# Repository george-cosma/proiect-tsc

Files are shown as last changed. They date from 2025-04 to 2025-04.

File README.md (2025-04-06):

# Openbook - Proiect TSC - by Cosma George

Exploded view

## Block Diagram

Block Diagram

## Overview ESP32

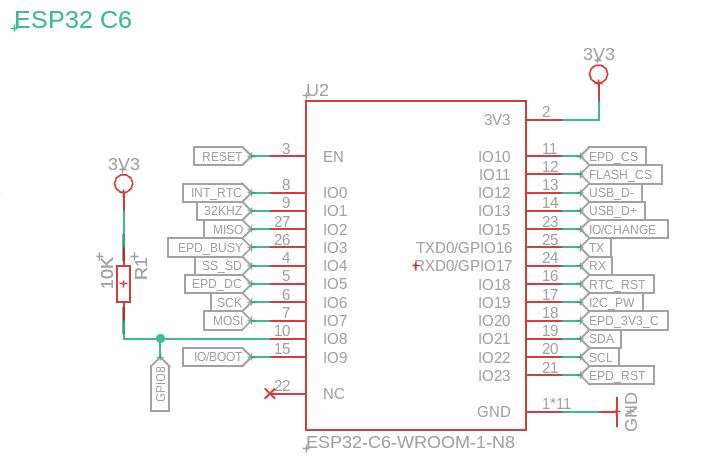
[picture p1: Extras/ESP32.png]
ESP32


1. **GND (All 11 pins)** - Connected to the ground plane
2. **3V3 (Pin 2)** - Connected to the 3.3V power rail
3. **EN (Pin 3)** - Enable pin - activates the ESP32-C6 when power is applied.
4. **IO0 (Pin 8)** - INT_RTC (RTC Interrupt) connects to the RTC module to receive time-based interrupts
5. **IO1 (Pin 9)** - 32KHz clock signal received from Oscilator
6. **IO2 (Pin 27)** - MISO (SPI Master In Slave Out). Connects to External Storage, External I/O and E-Paper Display Header
7. **IO3 (Pin 26)** - EPD_BUSY connects to the E-Paper display's busy signal to monitor when the display is busy
8. **IO4 (Pin 4)** - SS_SD (SD Card Chip Select)
9. **IO5 (Pin 5)** - EPD_DC (E-Paper Display Data/Command) to command the E-Paper Display via the Header
10. **IO6 (Pin 6)** - SCK (SPI Clock) to provide a clock frame of reference to communicate via SPI
11. **IO7 (Pin 7)** - MOSI (SPI Master Out Slave In) Connects to External Storage, External I/O and E-Paper Display Header
12. **IO8 (Pin 10)** - GPIO8 general purpose I/O, connected to a test pad (?)
13. **IO9 (Pin 15)** - IO/BOOT connected to an external push button with pull-up resistors.
14. **I10 (Pin 11)** - EPD_CS (E-Paper Display Chip Select) connects directly to the E-Paper Display Header to select when comunicating/receiving data from it.
15. **IO11 (Pin 11)** - FLASH_CS (SPI Flash Chip Select) connects to the NOR Flash memory to select when communicating/receiving data from it.
16. **IO12 (Pin 12)** - USB_D- (USB Data-) connects directly to the USB-C connector and is used for USB communication via UART.
17. **IO13 (Pin 13)** - USB_D+ (USB Data+) connects directly to the USB-C connector and is used for USB communication via UART.
18. **IO15 (Pin 14)** - IO/CHANGE connected to a push button with pull-up resistors, for user input
19. **TXD0/GPIO16 (Pin 25)** - TX (UART Transmit) connected to test pads - for debugging or programming
20. **RXD0/GPIO17 (Pin 24)** - RX (UART Receive) connected to test pads - for debugging or programming
21. **IO18 (Pin 16)** - RTC_RST (RTC Reset) connects to the reset pin of the real-time clock module
22. **IO19 (Pin 17)** - I2C_PW (I2C Power control) controls power to the I2C peripherals
23. **IO20 (Pin 18)** - EPD_3V3_C (E-Paper Display 3.3V control) controls power to the E-Paper display via a transistor. Used to turn on/off the display to save power when not in use.
24. **IO21 (Pin 19)** - SDA (I2C Data) connects to the I2C peripherals for data communication
25. **IO22 (Pin 20)** - SCL (I2C Clock) connects to the I2C peripherals for clock signal
26. **IO23 (Pin 21)** - EPD_RST (E-Paper Display Reset) connects to the E-Paper display's reset pin to reset the display when needed

## Components overview

1. **ESP32-C6-WROOM-1-N8**
   - Purpose: Main microcontroller/SoC
   - Interfaces: Everything
2. **W25Q512JVEIQ**
   - Purpose: External NOR flash memory
   - Interface: SPI
3. **MAX17048G+T10**
   - Purpose: IC to monitor Li-Po battery level
   - Interface: I2C
4. **XC6220A331MR-G**
   - Purpose: LDO voltage regulator
   - Interface: None (power supply)
5. **USBLC6-2SC6Y**
   - Purpose: USB ESD protection IC
   - Interface: USB D+/D- UART lines
6. **MCP73831**
   - Purpose: Single-cell Li-Po battery charging controller
   - Interface: None (power supply)
7. **BME688**
   - Purpose: Environmental sensor
   - Interface: I2C
8. **BD5229G-TR + Buttons**
   - Purpose: Voltage supervisor + Buttons
   - Interface: GPIO
9. **DS3231SN**
   - Purpose: Real-time clock with crystal oscillator
   - Interface: I2C and GPIO
10. **112A-TAAR-R03_ATTEND**
    - Purpose: SD card slot for storage
    - Interface: SPI
11. **FH34SRJ-24S-0.5SH_99_**
    - Purpose: E-Paper Display Headder
    - Interface: SPI + GPIO
12. **SAMACSYS_PARTS_USB4110-GF-A**
    - Purpose: USB-C connector
    - Interface: USB D+/D- UART

## Bill of Materials

| Qty | Device | Value | Parts | Description | BUY | DATASHEET |
|-----|---|---|---|---|---|---|
| 1 | 112A-TAAR-R03_ATTEND | - | J4 | Micro SD Card Socket, Push-Push Type, Top Mount, SMT, H=1.83mm, 10u | [Buy here](https://www.tme.eu/ro/details/mcc-sdmicro/conectori-pentru-cartele/attend/112a-taar-r03/) | [Datasheet here](https://cdn.soselectronic.com/productdata/bd/ac/42954337/112a-taar-r03.pdf) |
| 1 | 744043680IND_4828-WE-TPC_WRE | 68uH | L1 | | [Buy here](https://ro.mouser.com/ProductDetail/Wurth-Elektronik/744043008?qs=PGXP4M47uW6hG5GeMvqOSQ%3D%3D) | [Datasheet here](https://www.we-online.com/components/products/datasheet/744043008.pdf) |
| 1 | ADAFRUIT_LEDCHIP-LED0603 | - | CHG_LED | LED | [Buy here](https://ro.mouser.com/ProductDetail/ROHM-Semiconductor/CSL1104WBBW1?qs=DRkmTr78QAQ%252BqzFWy9Kqog%3D%3D) | [Datasheet here](https://fscdn.rohm.com/en/products/databook/datasheet/opto/led/chip_mono/csl1104wbbw1-e.pdf) |
| 2 | AVX SD0805S020S1R0 | - | D2, D7 | Schottky Barrier Rectifier Diode | [Buy here](https://ro.mouser.com/ProductDetail/KYOCERA-AVX/SD0805S020S1R0?qs=jCA%252BPfw4LHbpkAoSnwrdjw%3D%3D) | [Datasheet here](https://ro.mouser.com/datasheet/2/40/schottky-3165252.pdf) |
| 1 | BD5229G-TR | - | IC1 | Voltage Detector with Adjustable Delay Time | [Buy here](https://ro.mouser.com/ProductDetail/ROHM-Semiconductor/BD5229G-TR?qs=4kLU8WoGk0vvnhrrYwdszw%3D%3D) | [Datasheet here](https://fscdn.rohm.com/en/products/databook/datasheet/ic/power/voltage_detector/bd52xxg-e.pdf) |
| 1 | BME688 | - | SENSOR2 | Integrated Environmental Unit | [Buy here](https://ro.mouser.com/ProductDetail/Bosch-Sensortec/BME688?qs=IS%252B4QmGtzzqQoVDscqwx3A%3D%3D) | [Datasheet here](https://ro.mouser.com/datasheet/2/783/bst_bme688_fl000-2307034.pdf) |
| 1 | Button | BOOT_BUTTON, CHANGE_BUTTON_ RESET_BUTTON | U$1, U$2, U$3 | | [Buy here](https://ro.mouser.com/ProductDetail/Panasonic/EVQ-9P701P?qs=NPkb10g2yLBKCwpELvsGNg%3D%3D) | [Datasheet here](https://4donline.ihs.com/images/VipMasterIC/IC/PANA/PANAS45028/PANAS45028-1.pdf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) |
| 1 | Capacitor | 0.1uF/50V | EPD_C5 | CAPACITOR, European symbol | [Buy here](https://ro.mouser.com/ProductDetail/WIMA/SMDIC03100KA00MP00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) | [Datasheet here](https://ro.mouser.com/datasheet/2/440/e_WIMA_SMD_PPS-1139945.pdf) |
| 8 | Capacitor | 100nF | C1, C2, C4_USB, C6, C8, C9, C10, C_DELAY | CAPACITOR, European symbol | [Buy here](https://ro.mouser.com/ProductDetail/Vishay-Vitramon/VJ1210Y104KBBAT4X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) | [Datasheet here](https://www.vishay.com/doc?45198) |
| 1 | Capacitor | 10uF | C7 | CAPACITOR, European symbol | [Buy here](https://ro.mouser.com/ProductDetail/KYOCERA-AVX/KGM03DS60E106MH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) | [Datasheet here](https://ro.mouser.com/datasheet/2/40/cx5r_KGM-3223198.pdf) |
| 1 | Capacitor | 1uF | C5 | CAPACITOR, European symbol | [Buy here](https://ro.mouser.com/ProductDetail/WIMA/SMDTC04100VA00KR00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) | [Datasheet here](https://ro.mouser.com/datasheet/2/440/e_WIMA_SMD_PET-1139826.pdf) |
| 9 | Capacitor | 1uF/50V | EPD_C1, EPD_C2, EPD_C6, EPD_C7, EPD_C8, EPD_C9, EPD_C10, EPD_C11, EPD_C12 | CAPACITOR, European symbol | [Buy here](https://ro.mouser.com/ProductDetail/WIMA/SMDTC04100VA00KR00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) | [Datasheet here](https://ro.mouser.com/datasheet/2/440/e_WIMA_SMD_PET-1139826.pdf) |
| 5 | Capacitor | 4.7uF | C1_BAT, C1_BAT1, C1_BAT2, C2_BAT, C5_USB | CAPACITOR, European symbol | [Buy here](https://ro.mouser.com/ProductDetail/WIMA/SMDTD04470YA00KS00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) | [Datasheet here](https://ro.mouser.com/datasheet/2/440/e_WIMA_SMD_PET-1139826.pdf) |
| 1 | Capacitor | 4.7uF/25V | C4 | CAPACITOR, European symbol | [Buy here](https://ro.mouser.com/ProductDetail/WIMA/SMDTD04470YA00KS00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) | [Datasheet here](https://ro.mouser.com/datasheet/2/440/e_WIMA_SMD_PET-1139826.pdf) |
| 1 | CPH3225A | - | C10_SUPERCAP | Cap 0.011F 3.3V 1210 Flat Check availability | [Buy here](https://ro.mouser.com/ProductDetail/Seiko-Semiconductors/CPH3225A?qs=3etwrb1wR%252BhUOph6lAO7eg%3D%3D) | [Datasheet here](https://ro.mouser.com/datasheet/2/360/Seiko_Instruments_MicroBattery_E_20230330_2024Jan_-3561061.pdf) |
| 2 | DMG2305UX-7 | 20V/4.2A/52mO/1.4W | Q1, Q2 | P-channel MOSFETs | [Buy here](https://ro.mouser.com/ProductDetail/Diodes-Incorporated/DMG2305UX-7?qs=L1DZKBg7t5F%2FNBHrjfxC%252Bg%3D%3D) | [Datasheet here](https://www.diodes.com/assets/Datasheets/DMG2305UX.pdf) |
| 1 | DS3231SN# | - | U3 | Real Time Clock Serial 16-Pin SOIC W T/R Check availability | [Buy here](https://ro.mouser.com/ProductDetail/Analog-Devices-Maxim-Integrated/DS3231SN?qs=1eQvB6Dk1vhUlr8%2FOrV0Fw%3D%3D) | [Datasheet here](https://ro.mouser.com/datasheet/2/609/DS3231-3421123.pdf) |
| 1 | ESP32-C6-WROOM-1-N8 | - | U2 | | [Buy here](https://ro.mouser.com/ProductDetail/Espressif-Systems/ESP32-C6-WROOM-1-N8?qs=8Wlm6%252BaMh8ST02Gmwp74cw%3D%3D) | [Datasheet here](https://ro.mouser.com/datasheet/2/891/Espressif_ESP32_C6_WROOM_1__Datasheet_V0_1_PRELIMI-3239987.pdf) |
| 1 | FH34SRJ-24S-0.5SH_99_ | - | J1 |  (0.50mm) Surface Mount, Right Angle | [Buy here](https://ro.mouser.com/ProductDetail/Hirose-Connector/FH34SRJ-24S-0.5SH99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) | [Datasheet here](https://ro.mouser.com/datasheet/2/185/FH34SRJ_24S_0_5SH_99__CL0580_1255_6_99_2DDrawing_0-1615044.pdf) |
| 1 | MAX17048G+T10 | - | U4 | | [Buy here](https://ro.mouser.com/ProductDetail/Analog-Devices-Maxim-Integrated/MAX17048G%2bT10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) | [Datasheet here](https://ro.mouser.com/datasheet/2/609/MAX17048_MAX17049-3469099.pdf) |
| 3 | MBR0530 | - | D3, D4, D5 | ON SEMICONDUCTOR - MBR0530 - DIODE, SCHOTTKY, 0.5A, 30V, SOD-123 | [Buy here](https://ro.mouser.com/ProductDetail/onsemi/MBR0530T3G?qs=3JMERSakebpEmdUS6GetdQ%3D%3D) | [Datasheet here](https://www.onsemi.com/PowerSolutions/product.do?id=MBR0530T3G) |
| 1 | MCP73831 | - | U10 | MCP73831T Li-Ion, Li-Pol Controller | [Buy here](https://ro.mouser.com/ProductDetail/Microchip-Technology/MCP73831T-2ACI-OT?qs=yUQqVecv4qvbBQBGbHx0Mw%3D%3D) | [Datasheet here](https://ro.mouser.com/datasheet/2/268/MCP73831_Family_Data_Sheet_DS20001984H-3441711.pdf) |
| 6 | PGB1010603MR | - | D6, D8, D9, D10, D11, D12 | | [Buy here](https://ro.mouser.com/ProductDetail/Littelfuse/PGB1010603MR?qs=gu7KAQ731URLg4GSnNNN7Q%3D%3D) | [Datasheet here](https://www.littelfuse.com/assetdocs/pulseguard-esd-suppressors-pgb1-datasheet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) |
| 1 | QWIIC_CONNECTORJS-1MM | - | J3 | SparkFun I2C Standard Qwiic Connector | [Buy here](https://www.sparkfun.com/qwiic-jst-connector-smd-4-pin-horizontal.html) | [Datasheet here](https://cdn.sparkfun.com/assets/parts/1/2/2/8/9/Qwiic_Connector_Datasheet.pdf) |
| 1 | RCL_CPOL-EUCT3528 | 100uF TANT | C3 | POLARIZED CAPACITOR, European symbol | [Buy here](https://ro.mouser.com/ProductDetail/Vishay-Sprague/593D107X9020E2TE3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) | [Datasheet here](https://www.vishay.com/doc?40005) |
| 1 | Resistance | 0.47 | R3 | RESISTOR, European symbol | [Buy here](https://ro.mouser.com/ProductDetail/Panasonic/ERJ-14BQFR47U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) | [Datasheet here](https://industrial.panasonic.com/cdbs/www-data/pdf/RDN0000/AOA0000C313.pdf) |
| 1 | Resistance | 100K | R1_PWRBUS | RESISTOR, European symbol | [Buy here](https://ro.mouser.com/ProductDetail/Vishay-Thin-Film/PTN0603E1003BBT1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) | [Datasheet here](https://www.vishay.com/doc?60026) |
| 16  | Resistance | 10K | R1, R1_PINH, R1_PINH1, R2_PINH, R2_PINH1, R4, R5, R6, R7, R8, R9, R10, R_BOOT, R_CHANGE, R_CL1, R_RESET | RESISTOR, European symbol | [Buy here](https://ro.mouser.com/ProductDetail/Vishay-Draloric/RCA040210K0JNED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) | [Datasheet here](https://www.vishay.com/doc?20037) |
| 1 | Resistance | 15 | R_CAPACITOR | RESISTOR, European symbol | [Buy here](https://ro.mouser.com/ProductDetail/ROHM-Semiconductor/KTR03EZPJ150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) | [Datasheet here](https://www.rohm.com/datasheet?p=KTR03EZPJ&dist=Mouser&media=referral&source=mouser.com&campaign=Mouser) |
| 1 | Resistance | 2.2 | R2 | RESISTOR, European symbol | [Buy here](https://ro.mouser.com/ProductDetail/ROHM-Semiconductor/KTR18EZPJ2R2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) | [Datasheet here](https://www.rohm.com/datasheet?p=KTR18EZPJ&dist=Mouser&media=referral&source=mouser.com&campaign=Mouser) |
| 1 | Resistance | 200 | R1_BAT | RESISTOR, European symbol | [Buy here](https://ro.mouser.com/ProductDetail/ROHM-Semiconductor/KTR10EZPJ201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) | [Datasheet here](https://www.rohm.com/datasheet?p=KTR10EZPJ&dist=Mouser&media=referral&source=mouser.com&campaign=Mouser) |
| 1 | Resistance | 2K | R2_BAT | RESISTOR, European symbol | [Buy here](https://ro.mouser.com/ProductDetail/Vishay-Sfernice/P0805Y2001BBW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) | [Datasheet here](https://4donline.ihs.com/images/VipMasterIC/IC/VISH/VISH-S-A0007087424/VISH-S-A0007087424-1.pdf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) |
| 2 | Resistance | 5K1 | R2-USB, R2-USB1 | RESISTOR, European symbol | [Buy here](https://ro.mouser.com/ProductDetail/Vishay-Dale/TNPW04025K10BYEP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) | [Datasheet here](https://www.vishay.com/doc?28758) |
| 1 | SAMACSYS_PARTS_USB4110-GF-A  | - | J2 | CONN USB 2.0 TYPE-C R/A SMT | [Buy here](https://ro.mouser.com/ProductDetail/GCT/USB4110-GF-A?qs=KUoIvG%2F9IlYiZvIXQjyJeA%3D%3D) | [Datasheet here](https://ro.mouser.com/datasheet/2/837/GCT_USB4110_Product_Drawing___20k_cycles-3455479.pdf) |
| 1 | SI1308EDL-T1-GE3 | - | Q3 | MOSFET N-Ch 30V 1.5A TrenchFET SC70 Vishay Si1308EDL-T1-GE3 N-channel MOSFET Transistor, 1.5 A, 30 V, 3-Pin SC-70 | [Buy here](https://ro.mouser.com/ProductDetail/Vishay-Semiconductors/SI1308EDL-T1-GE3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) | [Datasheet here](https://www.vishay.com/doc?63399) |
| 1 | USBLC6-2SC6Y | - | D1 | Low Cap. ESD Protection Auto SOT-23-6 STMicroelectronics USBLC6-2SC6Y, Dual Uni-Directional TVS Diode Array, 6-Pin SOT-23 | [Buy here](https://ro.mouser.com/ProductDetail/STMicroelectronics/USBLC6-2SC6Y?qs=gNDSiZmRJS%2FOgDexvXkdow%3D%3D) | [Datasheet here](https://ro.mouser.com/datasheet/2/389/usblc6_2sc6y-1852505.pdf) |
| 1 | VARISTOR CN1812 | - | PFMF.050.1 | VARISTOR | [Buy here](https://ro.mouser.com/ProductDetail/Schurter/PFMF.050.2?qs=1auRipcfynCums5v1iucSA%3D%3D) | [Datasheet here](https://ro.mouser.com/datasheet/2/358/typ_PFMF-1275918.pdf) |
| 1 | W25Q512JVEIQ | - | U1 | | [Buy here](https://ro.mouser.com/ProductDetail/Winbond/W25Q512JVEIQ?qs=l7cgNqFNU1jw6svr3at6tA%3D%3D) | [Datasheet here](https://ro.mouser.com/datasheet/2/949/Winbond_W25Q512JV_Datasheet-3240039.pdf) |
| 1 | XC6220A331MR-G | - | IC4 | LDO Voltage Regulators | [Buy here](https://ro.mouser.com/ProductDetail/Torex-Semiconductor/XC6220A331MR-G?qs=AsjdqWjXhJ8ZSWznL1J0gg%3D%3D) | [Datasheet here](https://ro.mouser.com/datasheet/2/760/xc6220-3371556.pdf) |
| 1 | Battery | - | - | CELLEVIA BATTERIES LP584174, 3.7V 1800 mAh | [Buy here](https://www.tme.eu/ro/details/accu-lp584174_cl/acumulatori/cellevia-batteries/l584174/) | [Datasheet here](https://www.tme.eu/Document/e0683d8c34e6d878124489f71bffb6ee/cel0014.pdf) |
| 1 | E-Paper Display | - | - | 7.5''  800x480 px 125 DPI | [Buy here](https://www.waveshare.com/7.5inch-e-paper-hat.htm) | [Datasheet here](https://files.waveshare.com/upload/6/60/7.5inch_e-Paper_V2_Specification.pdf) |

## Implementation Notes/Details

- I've attempted to replicate the schematic as closely as possible, but there might be minor differences in terms of label size, label and text positioning,
compactness of components.
- The PCB was routed 100% manually, with no auto-router used. Both a top and bottom ground plane were used, as per the design requirements, and extensive via stitching was used to ensure a low-impedance ground connection. Via stiching can be removed if design parameters change, as additional vias for ground connectivity have been added to the design outside of the stiching process.
- Two visas were used for I2C_PW line, as it was unavoidable to route without crossing another power line. All power lines were routed using 0.3mm without vias and kept as short as possible, and all signal lines were routed using 0.2mm using vias.  
- PCB Thickness was modified to 1mm to ensure it, alongside the display, were able to fit within the given enclosure.
- PCB holes were added for the battery, ESP antenna, and the display header to allow for the ribbon cable to be inserted.
- Silkscreen was made with minimality in mind. Additional marks (lines, extra text) were added when needed to ensure readability.
- Accepted clearence error for USB-C connector.

## Other Images

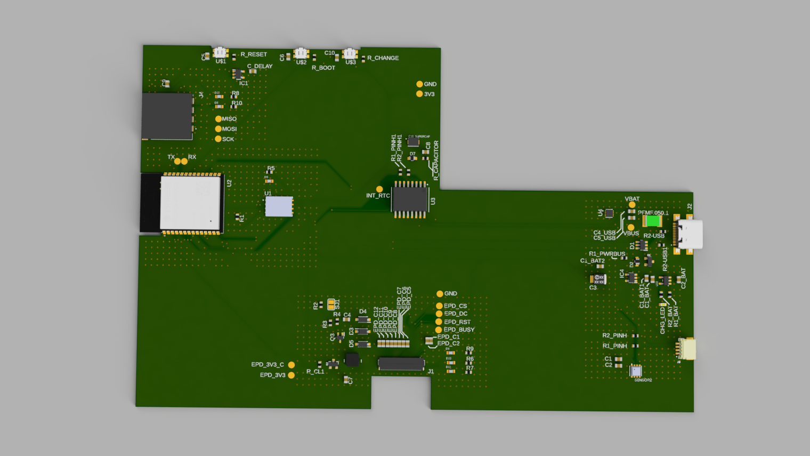
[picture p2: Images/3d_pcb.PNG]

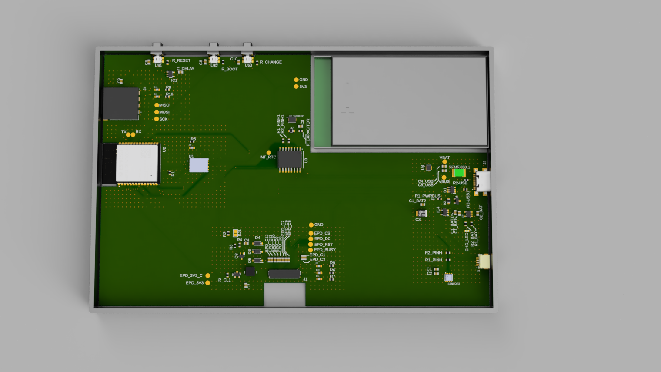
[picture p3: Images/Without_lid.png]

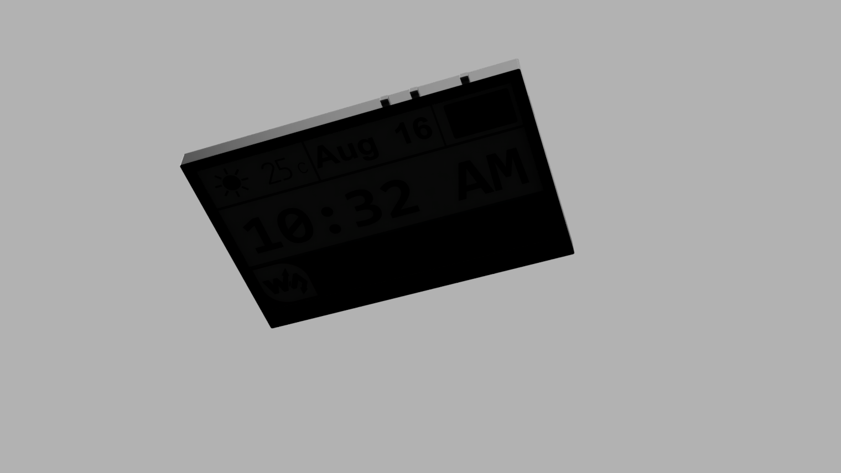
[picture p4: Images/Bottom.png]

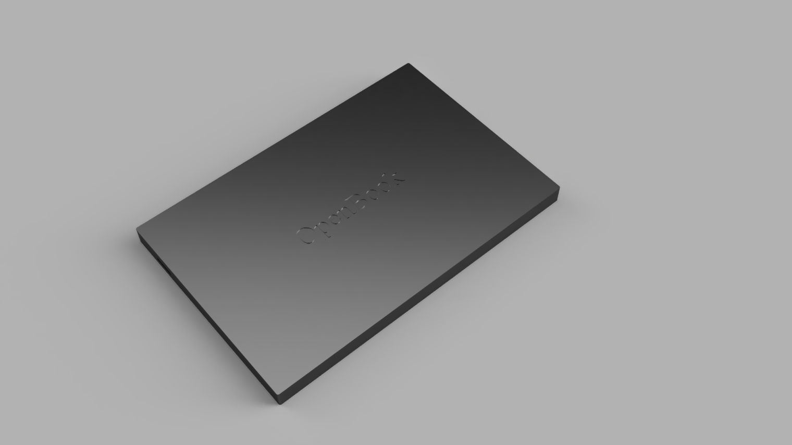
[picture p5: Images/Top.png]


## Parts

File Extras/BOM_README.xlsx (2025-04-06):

Qty | Device | Value | Parts | Description | BUY | DATASHEET
1 | 112A-TAAR-R03_ATTEND | - | J4 | Micro SD Card Socket, Push-Push Type, Top Mount, SMT, H=1.83mm, 10u | https://www.tme.eu/ro/details/mcc-sdmicro/conectori-pentru-cartele/attend/112a-taar-r03/ | https://cdn.soselectronic.com/productdata/bd/ac/42954337/112a-taar-r03.pdf
1 | 744043680IND_4828-WE-TPC_WRE | 68uH | L1 |  | https://ro.mouser.com/ProductDetail/Wurth-Elektronik/744043008?qs=PGXP4M47uW6hG5GeMvqOSQ%3D%3D | https://www.we-online.com/components/products/datasheet/744043008.pdf
1 | ADAFRUIT_LEDCHIP-LED0603 | - | CHG_LED | LED | https://ro.mouser.com/ProductDetail/ROHM-Semiconductor/CSL1104WBBW1?qs=DRkmTr78QAQ%252BqzFWy9Kqog%3D%3D | https://fscdn.rohm.com/en/products/databook/datasheet/opto/led/chip_mono/csl1104wbbw1-e.pdf
2 | AVX SD0805S020S1R0 | - | D2, D7 | Schottky Barrier Rectifier Diode | https://ro.mouser.com/ProductDetail/KYOCERA-AVX/SD0805S020S1R0?qs=jCA%252BPfw4LHbpkAoSnwrdjw%3D%3D | https://ro.mouser.com/datasheet/2/40/schottky-3165252.pdf
1 | BD5229G-TR | - | IC1 | Voltage Detector with Adjustable Delay Time | https://ro.mouser.com/ProductDetail/ROHM-Semiconductor/BD5229G-TR?qs=4kLU8WoGk0vvnhrrYwdszw%3D%3D | https://fscdn.rohm.com/en/products/databook/datasheet/ic/power/voltage_detector/bd52xxg-e.pdf
1 | BME688 | - | SENSOR2 | Integrated Environmental Unit | https://ro.mouser.com/ProductDetail/Bosch-Sensortec/BME688?qs=IS%252B4QmGtzzqQoVDscqwx3A%3D%3D | https://ro.mouser.com/datasheet/2/783/bst_bme688_fl000-2307034.pdf
1 | Button | BOOT_BUTTON, CHANGE_BUTTON_ RESET_BUTTON | U$1, U$2, U$3 |  | https://ro.mouser.com/ProductDetail/Panasonic/EVQ-9P701P?qs=NPkb10g2yLBKCwpELvsGNg%3D%3D | https://4donline.ihs.com/images/VipMasterIC/IC/PANA/PANAS45028/PANAS45028-1.pdf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
1 | Capacitor | 0.1uF/50V | EPD_C5 | CAPACITOR, European symbol | https://ro.mouser.com/ProductDetail/WIMA/SMDIC03100KA00MP00 | https://ro.mouser.com/datasheet/2/440/e_WIMA_SMD_PPS-1139945.pdf
8 | Capacitor | 100nF | C1, C2, C4_USB, C6, C8, C9, C10, C_DELAY | CAPACITOR, European symbol | https://ro.mouser.com/ProductDetail/Vishay-Vitramon/VJ1210Y104KBBAT4X | https://www.vishay.com/doc?45198
1 | Capacitor | 10uF | C7 | CAPACITOR, European symbol | https://ro.mouser.com/ProductDetail/KYOCERA-AVX/KGM03DS60E106MH | https://ro.mouser.com/datasheet/2/40/cx5r_KGM-3223198.pdf
1 | Capacitor | 1uF | C5 | CAPACITOR, European symbol | https://ro.mouser.com/ProductDetail/WIMA/SMDTC04100VA00KR00 | https://ro.mouser.com/datasheet/2/440/e_WIMA_SMD_PET-1139826.pdf
9 | Capacitor | 1uF/50V | EPD_C1, EPD_C2, EPD_C6, EPD_C7, EPD_C8, EPD_C9, EPD_C10, EPD_C11, EPD_C12 | CAPACITOR, European symbol | https://ro.mouser.com/ProductDetail/WIMA/SMDTC04100VA00KR00 | https://ro.mouser.com/datasheet/2/440/e_WIMA_SMD_PET-1139826.pdf
5 | Capacitor | 4.7uF | C1_BAT, C1_BAT1, C1_BAT2, C2_BAT, C5_USB | CAPACITOR, European symbol | https://ro.mouser.com/ProductDetail/WIMA/SMDTD04470YA00KS00 | https://ro.mouser.com/datasheet/2/440/e_WIMA_SMD_PET-1139826.pdf
1 | Capacitor | 4.7uF/25V | C4 | CAPACITOR, European symbol | https://ro.mouser.com/ProductDetail/WIMA/SMDTD04470YA00KS00 | https://ro.mouser.com/datasheet/2/440/e_WIMA_SMD_PET-1139826.pdf
1 | CPH3225A | - | C10_SUPERCAP | Cap 0.011F 3.3V 1210 Flat Check availability | https://ro.mouser.com/ProductDetail/Seiko-Semiconductors/CPH3225A?qs=3etwrb1wR%252BhUOph6lAO7eg%3D%3D | https://ro.mouser.com/datasheet/2/360/Seiko_Instruments_MicroBattery_E_20230330_2024Jan_-3561061.pdf
2 | DMG2305UX-7 | 20V/4.2A/52mO/1.4W | Q1, Q2 | P-channel MOSFETs | https://ro.mouser.com/ProductDetail/Diodes-Incorporated/DMG2305UX-7?qs=L1DZKBg7t5F%2FNBHrjfxC%252Bg%3D%3D | https://www.diodes.com/assets/Datasheets/DMG2305UX.pdf
1 | DS3231SN# | - | U3 | Real Time Clock Serial 16-Pin SOIC W T/R Check availability | https://ro.mouser.com/ProductDetail/Analog-Devices-Maxim-Integrated/DS3231SN?qs=1eQvB6Dk1vhUlr8%2FOrV0Fw%3D%3D | https://ro.mouser.com/datasheet/2/609/DS3231-3421123.pdf
1 | ESP32-C6-WROOM-1-N8 | - | U2 |  | https://ro.mouser.com/ProductDetail/Espressif-Systems/ESP32-C6-WROOM-1-N8?qs=8Wlm6%252BaMh8ST02Gmwp74cw%3D%3D | https://ro.mouser.com/datasheet/2/891/Espressif_ESP32_C6_WROOM_1__Datasheet_V0_1_PRELIMI-3239987.pdf
1 | FH34SRJ-24S-0.5SH_99_ | - | J1 | (0.50mm) Surface Mount, Right Angle | https://ro.mouser.com/ProductDetail/Hirose-Connector/FH34SRJ-24S-0.5SH99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 | https://ro.mouser.com/datasheet/2/185/FH34SRJ_24S_0_5SH_99__CL0580_1255_6_99_2DDrawing_0-1615044.pdf
1 | MAX17048G+T10 | - | U4 |  | https://ro.mouser.com/ProductDetail/Analog-Devices-Maxim-Integrated/MAX17048G%2bT10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 | https://ro.mouser.com/datasheet/2/609/MAX17048_MAX17049-3469099.pdf
3 | MBR0530 | - | D3, D4, D5 | ON SEMICONDUCTOR - MBR0530 - DIODE, SCHOTTKY, 0.5A, 30V, SOD-123 | https://ro.mouser.com/ProductDetail/onsemi/MBR0530T3G?qs=3JMERSakebpEmdUS6GetdQ%3D%3D | https://www.onsemi.com/PowerSolutions/product.do?id=MBR0530T3G
1 | MCP73831 | - | U10 | MCP73831T Li-Ion, Li-Pol Controller | https://ro.mouser.com/ProductDetail/Microchip-Technology/MCP73831T-2ACI-OT?qs=yUQqVecv4qvbBQBGbHx0Mw%3D%3D | https://ro.mouser.com/datasheet/2/268/MCP73831_Family_Data_Sheet_DS20001984H-3441711.pdf
6 | PGB1010603MR | - | D6, D8, D9, D10, D11, D12 |  | https://ro.mouser.com/ProductDetail/Littelfuse/PGB1010603MR?qs=gu7KAQ731URLg4GSnNNN7Q%3D%3D | https://www.littelfuse.com/assetdocs/pulseguard-esd-suppressors-pgb1-datasheet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
1 | QWIIC_CONNECTORJS-1MM | - | J3 | SparkFun I2C Standard Qwiic Connector | https://www.sparkfun.com/qwiic-jst-connector-smd-4-pin-horizontal.html | https://cdn.sparkfun.com/assets/parts/1/2/2/8/9/Qwiic_Connector_Datasheet.pdf
1 | RCL_CPOL-EUCT3528 | 100uF TANT | C3 | POLARIZED CAPACITOR, European symbol | https://ro.mouser.com/ProductDetail/Vishay-Sprague/593D107X9020E2TE3 | https://www.vishay.com/doc?40005
1 | Resistance | 0.47 | R3 | RESISTOR, European symbol | https://ro.mouser.com/ProductDetail/Panasonic/ERJ-14BQFR47U | https://industrial.panasonic.com/cdbs/www-data/pdf/RDN0000/AOA0000C313.pdf
1 | Resistance | 100K | R1_PWRBUS | RESISTOR, European symbol | https://ro.mouser.com/ProductDetail/Vishay-Thin-Film/PTN0603E1003BBT1 | https://www.vishay.com/doc?60026
16 | Resistance | 10K | R1, R1_PINH, R1_PINH1, R2_PINH, R2_PINH1, R4, R5, R6, R7, R8, R9, R10, R_BOOT, R_CHANGE, R_CL1, R_RESET | RESISTOR, European symbol | https://ro.mouser.com/ProductDetail/Vishay-Draloric/RCA040210K0JNED | https://www.vishay.com/doc?20037
1 | Resistance | 15 | R_CAPACITOR | RESISTOR, European symbol | https://ro.mouser.com/ProductDetail/ROHM-Semiconductor/KTR03EZPJ150 | https://www.rohm.com/datasheet?p=KTR03EZPJ&dist=Mouser&media=referral&campaign=Mouser
1 | Resistance | 2.2 | R2 | RESISTOR, European symbol | https://ro.mouser.com/ProductDetail/ROHM-Semiconductor/KTR18EZPJ2R2 | https://www.rohm.com/datasheet?p=KTR18EZPJ&dist=Mouser&media=referral&campaign=Mouser
1 | Resistance | 200 | R1_BAT | RESISTOR, European symbol | https://ro.mouser.com/ProductDetail/ROHM-Semiconductor/KTR10EZPJ201 | https://www.rohm.com/datasheet?p=KTR10EZPJ&dist=Mouser&media=referral&campaign=Mouser
1 | Resistance | 2K | R2_BAT | RESISTOR, European symbol | https://ro.mouser.com/ProductDetail/Vishay-Sfernice/P0805Y2001BBW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 | https://4donline.ihs.com/images/VipMasterIC/IC/VISH/VISH-S-A0007087424/VISH-S-A0007087424-1.pdf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
2 | Resistance | 5K1 | R2-USB, R2-USB1 | RESISTOR, European symbol | https://ro.mouser.com/ProductDetail/Vishay-Dale/TNPW04025K10BYEP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 | https://www.vishay.com/doc?28758
1 | SAMACSYS_PARTS_USB4110-GF-A | - | J2 | CONN USB 2.0 TYPE-C R/A SMT | https://ro.mouser.com/ProductDetail/GCT/USB4110-GF-A?qs=KUoIvG%2F9IlYiZvIXQjyJeA%3D%3D | https://ro.mouser.com/datasheet/2/837/GCT_USB4110_Product_Drawing___20k_cycles-3455479.pdf
1 | SI1308EDL-T1-GE3 | - | Q3 | MOSFET N-Ch 30V 1.5A TrenchFET SC70 Vishay Si1308EDL-T1-GE3 N-channel MOSFET Transistor, 1.5 A, 30 V, 3-Pin SC-70 | https://ro.mouser.com/ProductDetail/Vishay-Semiconductors/SI1308EDL-T1-GE3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 | https://www.vishay.com/doc?63399
1 | USBLC6-2SC6Y | - | D1 | Low Cap. ESD Protection Auto SOT-23-6 STMicroelectronics USBLC6-2SC6Y, Dual Uni-Directional TVS Diode Array, 6-Pin SOT-23 | https://ro.mouser.com/ProductDetail/STMicroelectronics/USBLC6-2SC6Y?qs=gNDSiZmRJS%2FOgDexvXkdow%3D%3D | https://ro.mouser.com/datasheet/2/389/usblc6_2sc6y-1852505.pdf
1 | VARISTOR CN1812 | - | PFMF.050.1 | VARISTOR | https://ro.mouser.com/ProductDetail/Schurter/PFMF.050.2?qs=1auRipcfynCums5v1iucSA%3D%3D | https://ro.mouser.com/datasheet/2/358/typ_PFMF-1275918.pdf
1 | W25Q512JVEIQ | - | U1 |  | https://ro.mouser.com/ProductDetail/Winbond/W25Q512JVEIQ?qs=l7cgNqFNU1jw6svr3at6tA%3D%3D | https://ro.mouser.com/datasheet/2/949/Winbond_W25Q512JV_Datasheet-3240039.pdf
1 | XC6220A331MR-G | - | IC4 | LDO Voltage Regulators | https://ro.mouser.com/ProductDetail/Torex-Semiconductor/XC6220A331MR-G?qs=AsjdqWjXhJ8ZSWznL1J0gg%3D%3D | https://ro.mouser.com/datasheet/2/760/xc6220-3371556.pdf

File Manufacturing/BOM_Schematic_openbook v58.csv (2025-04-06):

Qty | Value | Device | Package | Parts | Description | ARROW_PART_NUMBER | ARROW_PRICE-STOCK | AVAILABILITY | CENTROID_NOT_SPECIFIED | CHECK_PRICES | COPYRIGHT | DATASHEET | DESCRIPTION | DIGIKEY_DESCRIPTION | DIGIKEY_PART_NUMBER | HEIGHT | LEAD_FREE | MANUFACTURER_NAME | MANUFACTURER_PART_NUMBER | MF | MFR_NAME | MOUSER_PART_NUMBER | MOUSER_PRICE-STOCK | MOUSER_TESTING_PART_NUMBER | MOUSER_TESTING_PRICE-STOCK | MP | MPN | PACKAGE | POPULARITY | PREFIX | PRICE | PROD_ID | PURCHASE-URL | ROHS | SNAPEDA_LINK | SPICEMODEL | SPICEPREFIX | TEMPERATURE_RANGE_HIGH | TEMPERATURE_RANGE_LOW | TP_SIGNAL_NAME | VALUE
1 |  | ADAFRUIT_LEDCHIP-LED0603 | ADAFRUIT_CHIP-LED0603 | CHG_LED | LED
1 |  | SJ | SJ | SJ1 | SMD solder JUMPER |  |  |  |  |  |  |  |  |  |  |  |  |  |  |  |  |  |  |  |  |  |  |  | 3
1 | 0.1uF/50V | EAGLE-LTSPICE_CC0402 | EAGLE-LTSPICE_C0402 | EPD_C5 | CAPACITOR, European symbol |  |  |  |  |  |  |  |  |  |  |  |  |  |  |  |  |  |  |  |  |  |  |  |  |  |  |  |  |  |  | NONE | C
1 | 0.47 | ESP32_WROVER_EAGLE-LTSPICE_RR0402 | ESP32_WROVER_EAGLE-LTSPICE_R0402 | R3 | RESISTOR, European symbol |  |  |  |  |  |  |  |  |  |  |  |  |  |  |  |  |  |  |  |  |  |  |  |  |  |  |  |  |  |  | NONE | R
1 | 100K | ESP32_WROVER_EAGLE-LTSPICE_RR0402 | ESP32_WROVER_EAGLE-LTSPICE_R0402 | R1_PWRBUS | RESISTOR, European symbol |  |  |  |  |  |  |  |  |  |  |  |  |  |  |  |  |  |  |  |  |  |  |  |  |  |  |  |  |  |  | NONE | R
8 | 100nF | EAGLE-LTSPICE_CC0402 | EAGLE-LTSPICE_C0402 | C1, C2, C4_USB, C6, C8, C9, C10, C_DELAY | CAPACITOR, European symbol |  |  |  |  |  |  |  |  |  |  |  |  |  |  |  |  |  |  |  |  |  |  |  |  |  |  |  |  |  |  | NONE | C
1 | 100uF TANT | RCL_CPOL-EUCT3528 | RCL_CT3528 | C3 | POLARIZED CAPACITOR, European symbol |  |  |  |  |  |  |  |  |  |  |  |  |  |  |  |  |  |  |  |  |  |  |  | 0 |  |  |  |  |  |  |  | C
15 | 10K | ESP32_WROVER_EAGLE-LTSPICE_RR0402 | ESP32_WROVER_EAGLE-LTSPICE_R0402 | R1, R1_PINH, R1_PINH1, R2_PINH, R2_PINH1, R5, R6, R7, R8, R9, R10, R_BOOT, R_CHANGE, R_CL1, R_RESET | RESISTOR, European symbol |  |  |  |  |  |  |  |  |  |  |  |  |  |  |  |  |  |  |  |  |  |  |  |  |  |  |  |  |  |  | NONE | R
1 | 10k | ESP32_WROVER_EAGLE-LTSPICE_RR0402 | ESP32_WROVER_EAGLE-LTSPICE_R0402 | R4 | RESISTOR, European symbol |  |  |  |  |  |  |  |  |  |  |  |  |  |  |  |  |  |  |  |  |  |  |  |  |  |  |  |  |  |  | NONE | R
1 | 10uF | EAGLE-LTSPICE_CC0402 | EAGLE-LTSPICE_C0402 | C7 | CAPACITOR, European symbol |  |  |  |  |  |  |  |  |  |  |  |  |  |  |  |  |  |  |  |  |  |  |  |  |  |  |  |  |  |  | NONE | C
1 | 112A-TAAR-R03_ATTEND | 112A-TAAR-R03_ATTEND | 112ATAARR03ATTEND | J4 | Micro SD Card Socket, Push-Push Type, Top Mount, SMT, H=1.83mm, 10u |  |  |  |  |  |  |  | Micro SD Card Socket | Push-Push Type | Top Mount | SMT | H=1.83mm | 10u |  |  | 1.9mm |  | ATTEND | 112A-TAAR-R03 ATTEND
1 | 15 | ESP32_WROVER_EAGLE-LTSPICE_RR0402 | ESP32_WROVER_EAGLE-LTSPICE_R0402 | R_CAPACITOR | RESISTOR, European symbol |  |  |  |  |  |  |  |  |  |  |  |  |  |  |  |  |  |  |  |  |  |  |  |  |  |  |  |  |  |  | NONE | R
1 | 1uF | EAGLE-LTSPICE_CC0402 | EAGLE-LTSPICE_C0402 | C5 | CAPACITOR, European symbol |  |  |  |  |  |  |  |  |  |  |  |  |  |  |  |  |  |  |  |  |  |  |  |  |  |  |  |  |  |  | NONE | C
9 | 1uF/50V | EAGLE-LTSPICE_CC0402 | EAGLE-LTSPICE_C0402 | EPD_C1, EPD_C2, EPD_C6, EPD_C7, EPD_C8, EPD_C9, EPD_C10, EPD_C11, EPD_C12 | CAPACITOR, European symbol |  |  |  |  |  |  |  |  |  |  |  |  |  |  |  |  |  |  |  |  |  |  |  |  |  |  |  |  |  |  | NONE | C
1 | 2.2 | ESP32_WROVER_EAGLE-LTSPICE_RR0402 | ESP32_WROVER_EAGLE-LTSPICE_R0402 | R2 | RESISTOR, European symbol |  |  |  |  |  |  |  |  |  |  |  |  |  |  |  |  |  |  |  |  |  |  |  |  |  |  |  |  |  |  | NONE | R
1 | 200 | ESP32_WROVER_EAGLE-LTSPICE_RR0402 | ESP32_WROVER_EAGLE-LTSPICE_R0402 | R1_BAT | RESISTOR, European symbol |  |  |  |  |  |  |  |  |  |  |  |  |  |  |  |  |  |  |  |  |  |  |  |  |  |  |  |  |  |  | NONE | R
2 | 20V/4.2A/52mO/1.4W | ESP32_WROVER_SPARKFUN-DISCRETESEMI_MOSFET_PCH-DMG2305UX-7 | ESP32_WROVER_SPARKFUN-DISCRETESEMI_SOT23-3 | Q1, Q2 | P-channel MOSFETs |  |  |  |  |  |  |  |  |  |  |  |  |  |  |  |  |  |  |  |  |  |  |  |  |  |  | TRAN-14388 |  |  |  |  |  |  |  |  | 20V/4.2A/52mO/1.4W
1 | 2K | ESP32_WROVER_EAGLE-LTSPICE_RR0402 | ESP32_WROVER_EAGLE-LTSPICE_R0402 | R2_BAT | RESISTOR, European symbol |  |  |  |  |  |  |  |  |  |  |  |  |  |  |  |  |  |  |  |  |  |  |  |  |  |  |  |  |  |  | NONE | R
5 | 4.7uF | EAGLE-LTSPICE_CC0402 | EAGLE-LTSPICE_C0402 | C1_BAT, C1_BAT1, C1_BAT2, C2_BAT, C5_USB | CAPACITOR, European symbol |  |  |  |  |  |  |  |  |  |  |  |  |  |  |  |  |  |  |  |  |  |  |  |  |  |  |  |  |  |  | NONE | C
1 | 4.7uF/25V | EAGLE-LTSPICE_CC0402 | EAGLE-LTSPICE_C0402 | C4 | CAPACITOR, European symbol |  |  |  |  |  |  |  |  |  |  |  |  |  |  |  |  |  |  |  |  |  |  |  |  |  |  |  |  |  |  | NONE | C
2 | 5K1 | ESP32_WROVER_EAGLE-LTSPICE_RR0402 | ESP32_WROVER_EAGLE-LTSPICE_R0402 | R2-USB, R2-USB1 | RESISTOR, European symbol |  |  |  |  |  |  |  |  |  |  |  |  |  |  |  |  |  |  |  |  |  |  |  |  |  |  |  |  |  |  | NONE | R
1 | 68uH | 744043680IND_4828-WE-TPC_WRE | IND_4828-WE-TPC_WRE | L1 |  |  |  |  |  |  | Copyright (C) 2024 Ultra Librarian. All rights reserved. |  |  |  |  |  |  |  | 744043680 |  | Wurth Electronics
1 | BD5229G-TR | BD5229G-TR | SOT95P280X125-5N | IC1 | Voltage Detector with Adjustable Delay Time: CMOS processes are utilized to develop high precision, low current consumption CMOS reset ICs that allow arbitrary setting of the delay time. The extensive lineup includes both Nch Open Drain and CMOS output types in a wide range of detection voltages (from 2.3V to 6.0V, in 0.1V steps), enabling selection of the ideal solution based on customer requirements. In addition, the entire series is of course both lead-free and RoHS-compliant. |  |  |  |  |  |  |  | Voltage Detector with Adjustable Delay Time: CMOS processes are utilized to develop high precision | low current consumption CMOS reset ICs that allow arbitrary setting of the delay time. The extensive lineup includes both Nch Open Drain and CMOS output types in a wide range of detection voltages (from 2.3V to 6.0V | in 0.1V steps) | enabling selection of the ideal solution based on customer requirements. In addition | the entire series is of course both lead-free and RoHS-compliant. |  |  | 1.25mm |  | ROHM Semiconductor | BD5229G-TR |  |  | 755-BD5229G-TR | https://www.mouser.co.uk/ProductDetail/ROHM-Semiconductor/BD5229G-TR?qs=4kLU8WoGk0vvnhrrYwdszw%3D%3D
1 | BME688 | ESP32_WROVER_BME680_BME680 | ESP32_WROVER_BME680_PSON80P300X300X100-8N | SENSOR2 | Integrated Environmental Unit |  |  | Unavailable |  |  |  |  | Integrated Environmental Unit |  |  |  |  |  |  | Bosch Sensortec |  |  |  |  |  | BME680 |  | LGA-8 Bosch Tools |  |  | None
1 | BOOT_BUTTON | BUTTON_CUSYOMV1 | MYBUTTON | U$2
1 | CHANGE_BUTTON | BUTTON_CUSYOMV1 | MYBUTTON | U$3
1 | CPH3225A | CPH3225A | CAPCP3225X100N | C10_SUPERCAP | Cap 0.011F 3.3V 1210 Flat Check availability |  |  | Not in stock |  | https://www.snapeda.com/parts/CPH3225A/Seiko+Instruments/view-part/?ref=eda |  |  | 11 mF (EDLC) Supercapacitor 3.3 V 1210 (3225 Metric) - - |  |  |  |  |  |  | Seiko Instruments |  |  |  |  |  | CPH3225A |  | 1210 Seiko |  |  | None |  | https://www.snapeda.com/api/url_track_click_mouser/?unipart_id=562593&manufacturer=Seiko Instruments&part_name=CPH3225A&search_term=None |  | https://www.snapeda.com/parts/CPH3225A/Seiko+Instruments/view-part/?ref=snap
1 | DS3231SN# | DS3231SN# | SOIC127P1032X265-16N | U3 | Real Time Clock Serial 16-Pin SOIC W T/R Check availability |  |  | In Stock |  | https://www.snapeda.com/parts/DS3231SN%23/Analog+Devices/view-part/?ref=eda |  |  | Extremely Accurate I²C-Integrated RTC/TCXO/Crystal |  |  |  |  |  |  | Analog Devices |  |  |  |  |  | DS3231SN# |  | SOIC-16 Maxim |  |  | None |  | https://www.snapeda.com/api/url_track_click_mouser/?unipart_id=99048&manufacturer=Analog Devices&part_name=DS3231SN#&search_term=None |  | https://www.snapeda.com/parts/DS3231SN%23/Analog+Devices/view-part/?ref=snap
1 | ESP32-C6-WROOM-1-N8 | ESP32-C6-WROOM-1-N8 | XCVR_ESP32-C6-WROOM-1-N8 | U2 | Check availability |  |  | In Stock |  | https://www.snapeda.com/parts/ESP32-C6-WROOM-1-N8/Espressif+Systems/view-part/?ref=eda |  |  | Multiprotocol Modules ESP32-C6 module | Wi-Fi 6 in 2.4 GHz band | Bluetooth 5 | Zigbee 3.0 and Thread. ESP34-WROOM Compatible - ENGINEERING SAMPLE |  |  |  |  |  |  | Espressif Systems |  |  |  |  |  | ESP32-C6-WROOM-1-N8 |  | None |  |  | None |  |  |  | https://www.snapeda.com/parts/ESP32-C6-WROOM-1-N8/Espressif+Systems/view-part/?ref=snap
1 | ESP32C6_VARISTORCN1812 | ESP32C6_VARISTORCN1812 | ESP32C6_VARISTOR_CT/CN1812 | PFMF.050.1 | VARISTOR |  |  |  |  |  |  |  |  |  |  |  |  |  |  |  |  |  |  |  |  |  |  |  | 0
1 | ESP32_WROVER_AVX---SD0805S020S1R0_AVX_SD0805S020S1R0_0_0AVX_SD0805S020S1R0_0_0 | ESP32_WROVER_AVX---SD0805S020S1R0_AVX_SD0805S020S1R0_0_0AVX_SD0805S020S1R0_0_0 | ESP32_WROVER_AVX---SD0805S020S1R0_AVX_SD0805S020S1R0_0 | D2 | Schottky Barrier Rectifier Diode |  |  |  | No |  |  | http://datasheets.avx.com/schottky.pdf |  | DIODE SCHOTTKY 20V 1A 0805 | 478-7800-1-ND |  | yes |  |  | AVX |  | 581-SD0805S020S1R0 |  |  |  |  |  | 0805 (2012 metric) |  | D |  |  |  | yes |  |  |  | +125°C | -55°C
1 | FH34SRJ-24S-0.5SH_99_ | FH34SRJ-24S-0.5SH_99_ | FH34SRJ24S05SH99 | J1 | (0.50mm) Surface Mount, Right Angle |  |  |  |  |  |  |  | 24 Position FFC | FPC Connector Contacts | (0.50mm) Surface Mount | Right Angle |  |  | 1.1mm |  | Hirose | FH34SRJ-24S-0.5SH(99) |  |  | 798-FH34SRJ24S05SH99 | https://www.mouser.co.uk/ProductDetail/Hirose-Connector/FH34SRJ-24S-0.5SH99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
1 | MAX17048G+T10 | MAX17048G+T10 | SON50P200X200X80-9N | U4 | Check availability |  |  | In Stock |  | https://www.snapeda.com/parts/MAX17048G+T10/Analog+Devices/view-part/?ref=eda |  |  | 3µA 1-Cell/2-Cell Fuel Gauge with ModelGauge |  |  |  |  |  |  | Analog Devices |  |  |  |  |  | MAX17048G+T10 |  | TDFN-8 Maxim |  |  | None |  | https://www.snapeda.com/api/url_track_click_mouser/?unipart_id=329239&manufacturer=Analog Devices&part_name=MAX17048G+T10&search_term=None |  | https://www.snapeda.com/parts/MAX17048G+T10/Analog+Devices/view-part/?ref=snap
3 | MBR0530 | MBR0530 | SOD3716X135N | D3, D4, D5 | ON SEMICONDUCTOR - MBR0530 - DIODE, SCHOTTKY, 0.5A, 30V, SOD-123 |  |  | In Stock |  | https://www.snapeda.com/parts/MBR0530/Onsemi/view-part/?ref=eda |  |  | Diode Schottky 30 V 500mA Surface Mount SOD-123 |  |  |  |  |  |  | ON Semiconductor |  |  |  |  |  | MBR0530 |  | SOD-123-2 ON Semiconductor |  |  | None |  | https://www.snapeda.com/api/url_track_click_mouser/?unipart_id=179458&manufacturer=ON Semiconductor&part_name=MBR0530&search_term=None |  | https://www.snapeda.com/parts/MBR0530/Onsemi/view-part/?ref=snap
1 | MCP73831 | ESP32_WROVER_SPARKFUN-IC-POWER_MCP73831 | ESP32_WROVER_SPARKFUN-IC-POWER_SOT23-5 | U10 | MCP73831T Li-Ion, Li-Pol Controller |  |  |  |  |  |  |  |  |  |  |  |  |  |  |  |  |  |  |  |  |  |  |  |  |  |  | IC-09995
6 | PGB1010603MR | PGB1010603MR | DIOC1608X36N | D6, D8, D9, D10, D11, D12 | Check availability |  |  | In Stock |  | https://www.snapeda.com/parts/PGB1010603MR/Littelfuse/view-part/?ref=eda |  |  | 150V (Typ) Clamp - Ipp Tvs Diode Surface Mount 0603 (1608 Metric) |  |  |  |  |  |  | Littelfuse Inc. |  |  |  |  |  | PGB1010603MR |  | 0603 Littelfuse Inc. |  |  | None |  | https://www.snapeda.com/api/url_track_click_mouser/?unipart_id=5659453&manufacturer=Littelfuse Inc.&part_name=PGB1010603MR&search_term=None |  | https://www.snapeda.com/parts/PGB1010603MR/Littelfuse/view-part/?ref=snap
1 | QWIIC_RIGHT_ANGLE | QWIIC_CONNECTORJS-1MM | JST04_1MM_RA | J3 | SparkFun I2C Standard Qwiic Connector |  |  |  |  |  |  |  |  |  |  |  |  |  |  |  |  |  |  |  |  |  |  |  |  |  |  | CONN-13694 |  |  |  |  |  |  |  |  | QWIIC_RIGHT_ANGLE
1 | RESET_BUTTON | BUTTON_CUSYOMV1 | MYBUTTON | U$1
1 | SAMACSYS_PARTS_USB4110-GF-A | SAMACSYS_PARTS_USB4110-GF-A | SAMACSYS_PARTS_USB4110GFA | J2 | CONN USB 2.0 TYPE-C R/A SMT |  |  |  |  |  |  |  | CONN USB 2.0 TYPE-C R/A SMT |  |  | 3.26mm |  | GCT (GLOBAL CONNECTOR TECHNOLOGY) | USB4110-GF-A |  |  | 640-USB4110-GF-A | https://www.mouser.co.uk/ProductDetail/GCT/USB4110-GF-A?qs=KUoIvG%2F9IlYiZvIXQjyJeA%3D%3D
1 | SD0805S020S1R0 | ESP32_WROVER_AVX---SD0805S020S1R0_AVX_SD0805S020S1R0_0_0AVX_SD0805S020S1R0_0_0 | ESP32_WROVER_AVX---SD0805S020S1R0_AVX_SD0805S020S1R0_0 | D7 | Schottky Barrier Rectifier Diode |  |  |  | No |  |  | http://datasheets.avx.com/schottky.pdf |  | DIODE SCHOTTKY 20V 1A 0805 | 478-7800-1-ND |  | yes |  |  | AVX |  | 581-SD0805S020S1R0 |  |  |  |  |  | 0805 (2012 metric) |  | D |  |  |  | yes |  |  |  | +125°C | -55°C
1 | SI1308EDL-T1-GE3 | SI1308EDL-T1-GE3 | SOT65P210X110-3N | Q3 | MOSFET N-Ch 30V 1.5A TrenchFET SC70 Vishay Si1308EDL-T1-GE3 N-channel MOSFET Transistor, 1.5 A, 30 V, 3-Pin SC-70 |  |  | In Stock |  | https://www.snapeda.com/parts/SI1308EDL-T1-GE3/Vishay+Siliconix/view-part/?ref=eda |  |  | Si1308EDL-T1-GE3 N-channel MOSFET Transistor | 1.5 A | 30 V | 3-Pin SC-70 | Siliconix / Vishay SI1308EDL-T1-GE3 |  |  |  |  |  |  | Vishay Siliconix |  |  |  |  |  | SI1308EDL-T1-GE3 |  | SOT-323 Vishay Semiconductor |  |  | None |  | https://www.snapeda.com/api/url_track_click_mouser/?unipart_id=274603&manufacturer=Vishay Siliconix&part_name=SI1308EDL-T1-GE3&search_term=None |  | https://www.snapeda.com/parts/SI1308EDL-T1-GE3/Vishay+Siliconix/view-part/?ref=snap
17 | TPTP20R | TPTP20R | TP20R | TP1, TP2, TP3, TP4, TP5, TP6, TP7, TP8, TP9, TP10, TP11, TP12, TP13, TP14, TP15, TP16, TP17 | Test pad |  |  |  |  |  |  |  |  |  |  |  |  |  |  |  |  |  |  |  |  |  |  |  | 2
1 | USBLC6-2SC6Y | USBLC6-2SC6Y | SOT95P280X145-6N | D1 | Low Cap. ESD Protection Auto SOT-23-6 STMicroelectronics USBLC6-2SC6Y, Dual Uni-Directional TVS Diode Array, 6-Pin SOT-23 |  |  | In Stock |  | https://www.snapeda.com/parts/USBLC6-2SC6Y/STMicroelectronics/view-part/?ref=eda |  |  | 17V Clamp 5A (8/20µs) Ipp Tvs Diode Surface Mount SOT-23-6 |  |  |  |  |  |  | STMicroelectronics |  |  |  |  |  | USBLC6-2SC6Y |  | SOT-23-6 STMicroelectronics |  |  | None |  |  |  | https://www.snapeda.com/parts/USBLC6-2SC6Y/STMicroelectronics/view-part/?ref=snap
1 | W25Q512JVEIQ | W25Q512JVEIQ | SON127P600X800X80-9N | U1 | Check availability |  |  | In Stock |  | https://www.snapeda.com/parts/W25Q512JVEIQ/Winbond+Electronics/view-part/?ref=eda |  |  | FLASH - NOR Memory IC 512Mb (64M x 8) SPI - Quad I/O 133 MHz 8-WSON (8x6) |  |  |  |  |  |  | Winbond Electronics |  |  |  |  |  | W25Q512JVEIQ |  | Package |  |  | None |  |  |  | https://www.snapeda.com/parts/W25Q512JVEIQ/Winbond+Electronics/view-part/?ref=snap
1 | XC6220A331MR-G | XC6220A331MR-G | SOT95P280X120-5N | IC4 | LDO Voltage Regulators |  |  |  |  |  |  |  | LDO Voltage Regulators |  |  | 1.2mm |  | Torex | XC6220A331MR-G |  |  | 865-XC6220A331MR-G | https://www.mouser.co.uk/ProductDetail/Torex-Semiconductor/XC6220A331MR-G?qs=AsjdqWjXhJ8ZSWznL1J0gg%3D%3D

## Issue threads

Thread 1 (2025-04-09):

Review

RaduTul, 2025-04-09:
# 1.Linia care separa componentele din schematic e trasa pe layerul gresit. (e trasa pe 91 NETS in loc de 97 INFO)
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
# 2.Numele componentelor din schematic e scris pe layerul gresit. (e scris pe 91 NETS in loc de 97 INFO)
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
# 3.Componenta incercuita nu e buna (vezi in poza)
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
# 4.Dupa verificarea ERC ai niste erori extra care pot fi rezolvate (cele incercuite nu le poti rezolva, poti la erorile de value sa pui o litera sau simbol)
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
# 5.Dupa verificarea DRC ai erori
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
# 6.La PCB C8 poate sa fie pus mai aproape de pinul de alimentare

george-cosma, 2025-04-13:
Done! Mersi pentru review!

Closed 2025-04-13.

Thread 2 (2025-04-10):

Review 2

RaduTul, 2025-04-10:
# thicknesull nu este de 1 mm (ca sa rezolvi te duci in pcb sus ai RULES dupa apesi layer stacks, bifezi in dreata sus edit material properties si schimbi thicknesul de la 1.6 la 1 mm)
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

george-cosma, 2025-04-10:
Hmmm se pare care unele chestii nu sunt stocate in `.brd`, caci pe local vad ca e setat (in total) 1.00 mm

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

Totusi, mersi ca te-ai uitat :)

P.S. O sa incerc sa fac review la tine in seara asta :D

RaduTul, 2025-04-10:
super te pup <3

RaduTul, 2025-04-10:
auzi daca poti sa ma adaugi si pe mine ca si colaborator ca sa pot pune label la issues. te adaug si pe tine la mine.

Closed 2025-04-10.

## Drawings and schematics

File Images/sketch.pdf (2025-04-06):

# 3V3 GND

D2

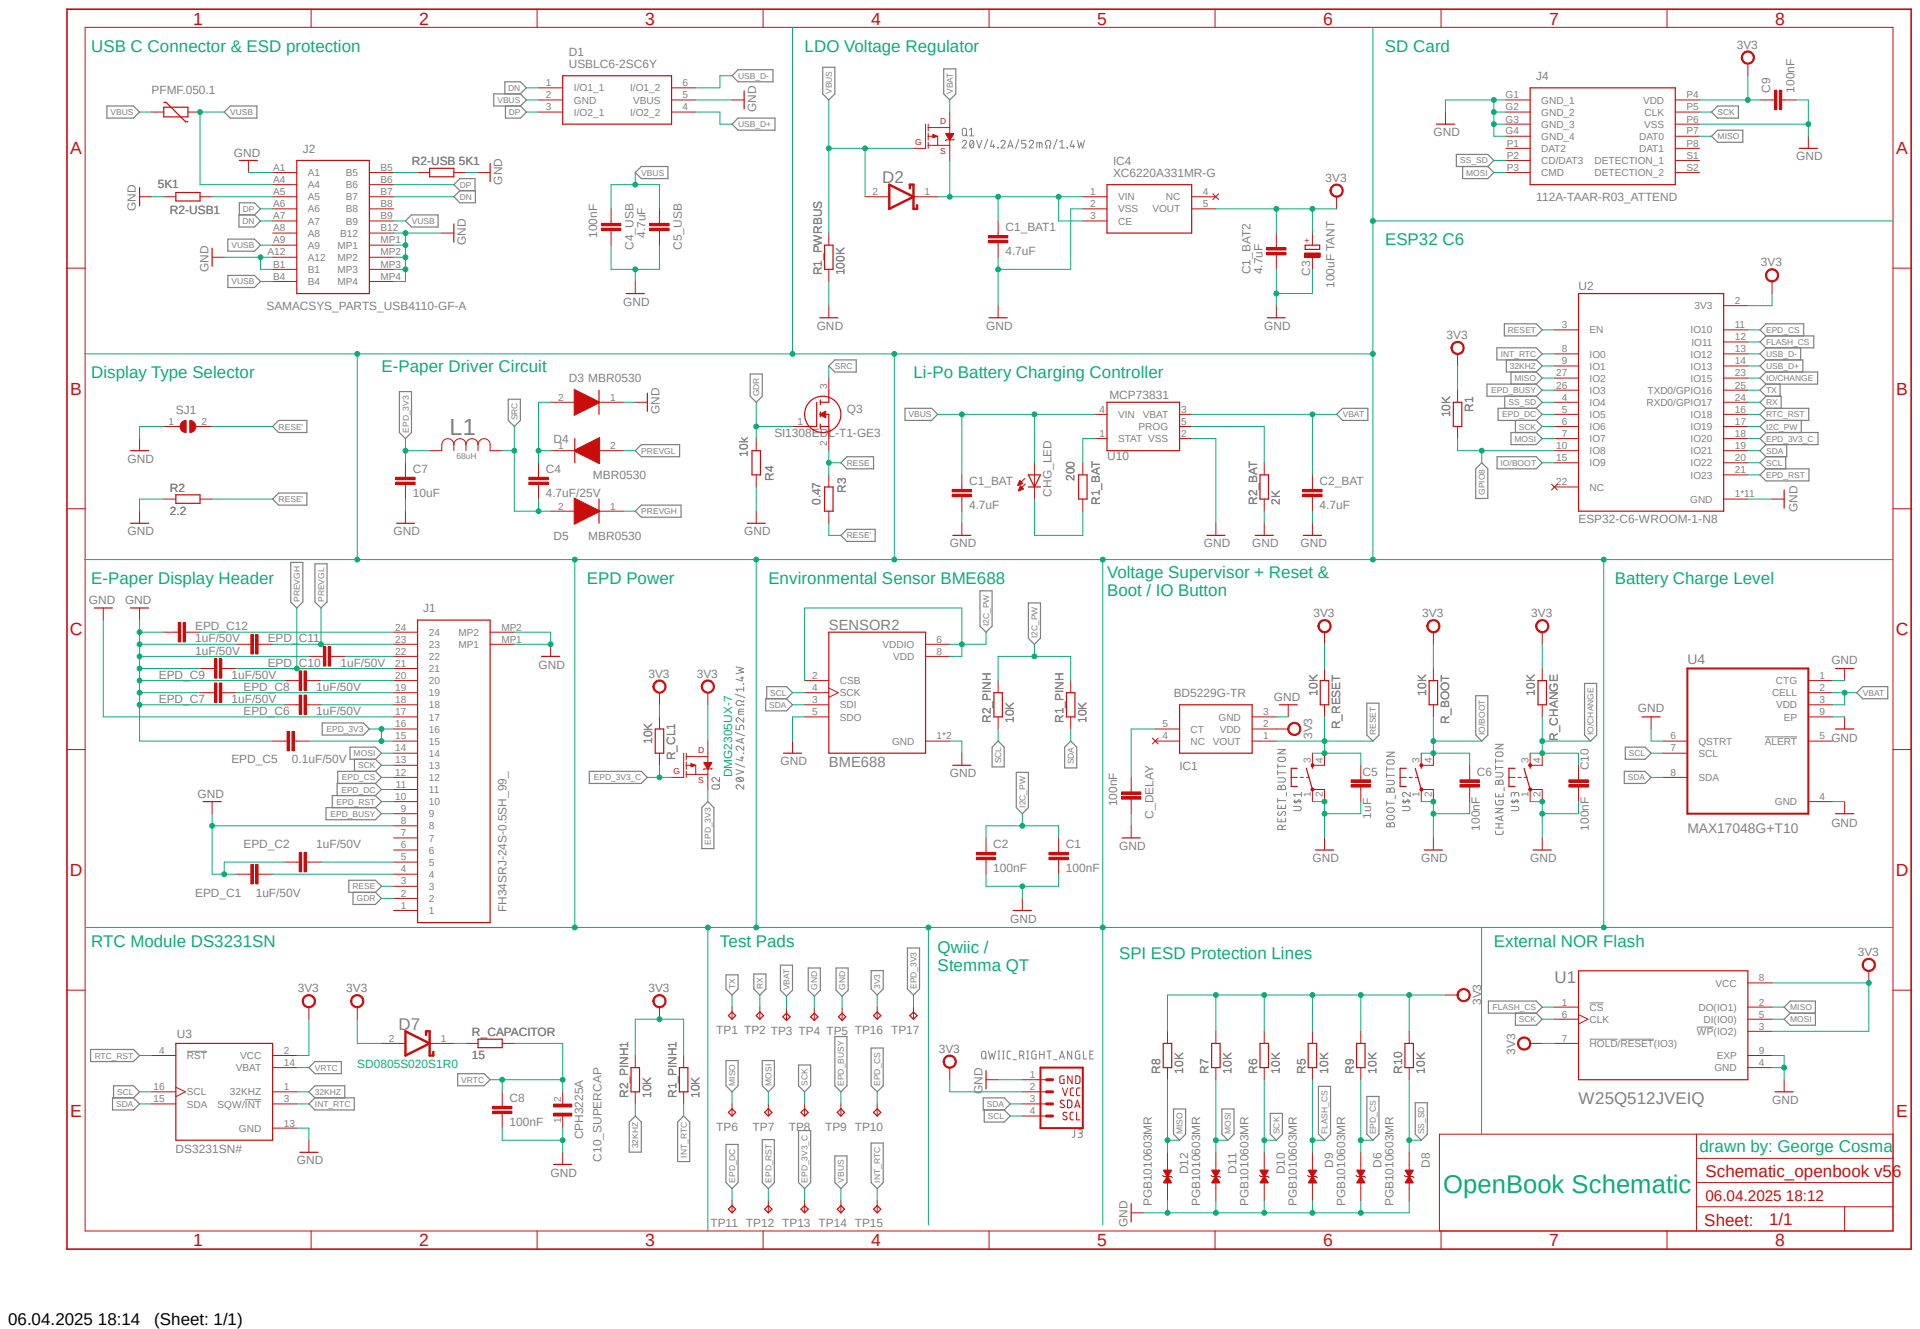
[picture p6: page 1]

ESP32 C6

IO/CHANGE

3 2 C1_BAT C2_BAT R1_BAT R2_BAT CHG_LED U10 PROG 5 STAT 1 VBAT 3 VIN 4 VSS 2

Boot / IO Button | Battery Charge Level U4 GND

EPD_C10 | 1uF/50V | GND

EPD_C7 | 1uF/50V

EPD_C6 | | 1uF/50V

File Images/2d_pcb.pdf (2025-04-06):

24.00

49.00

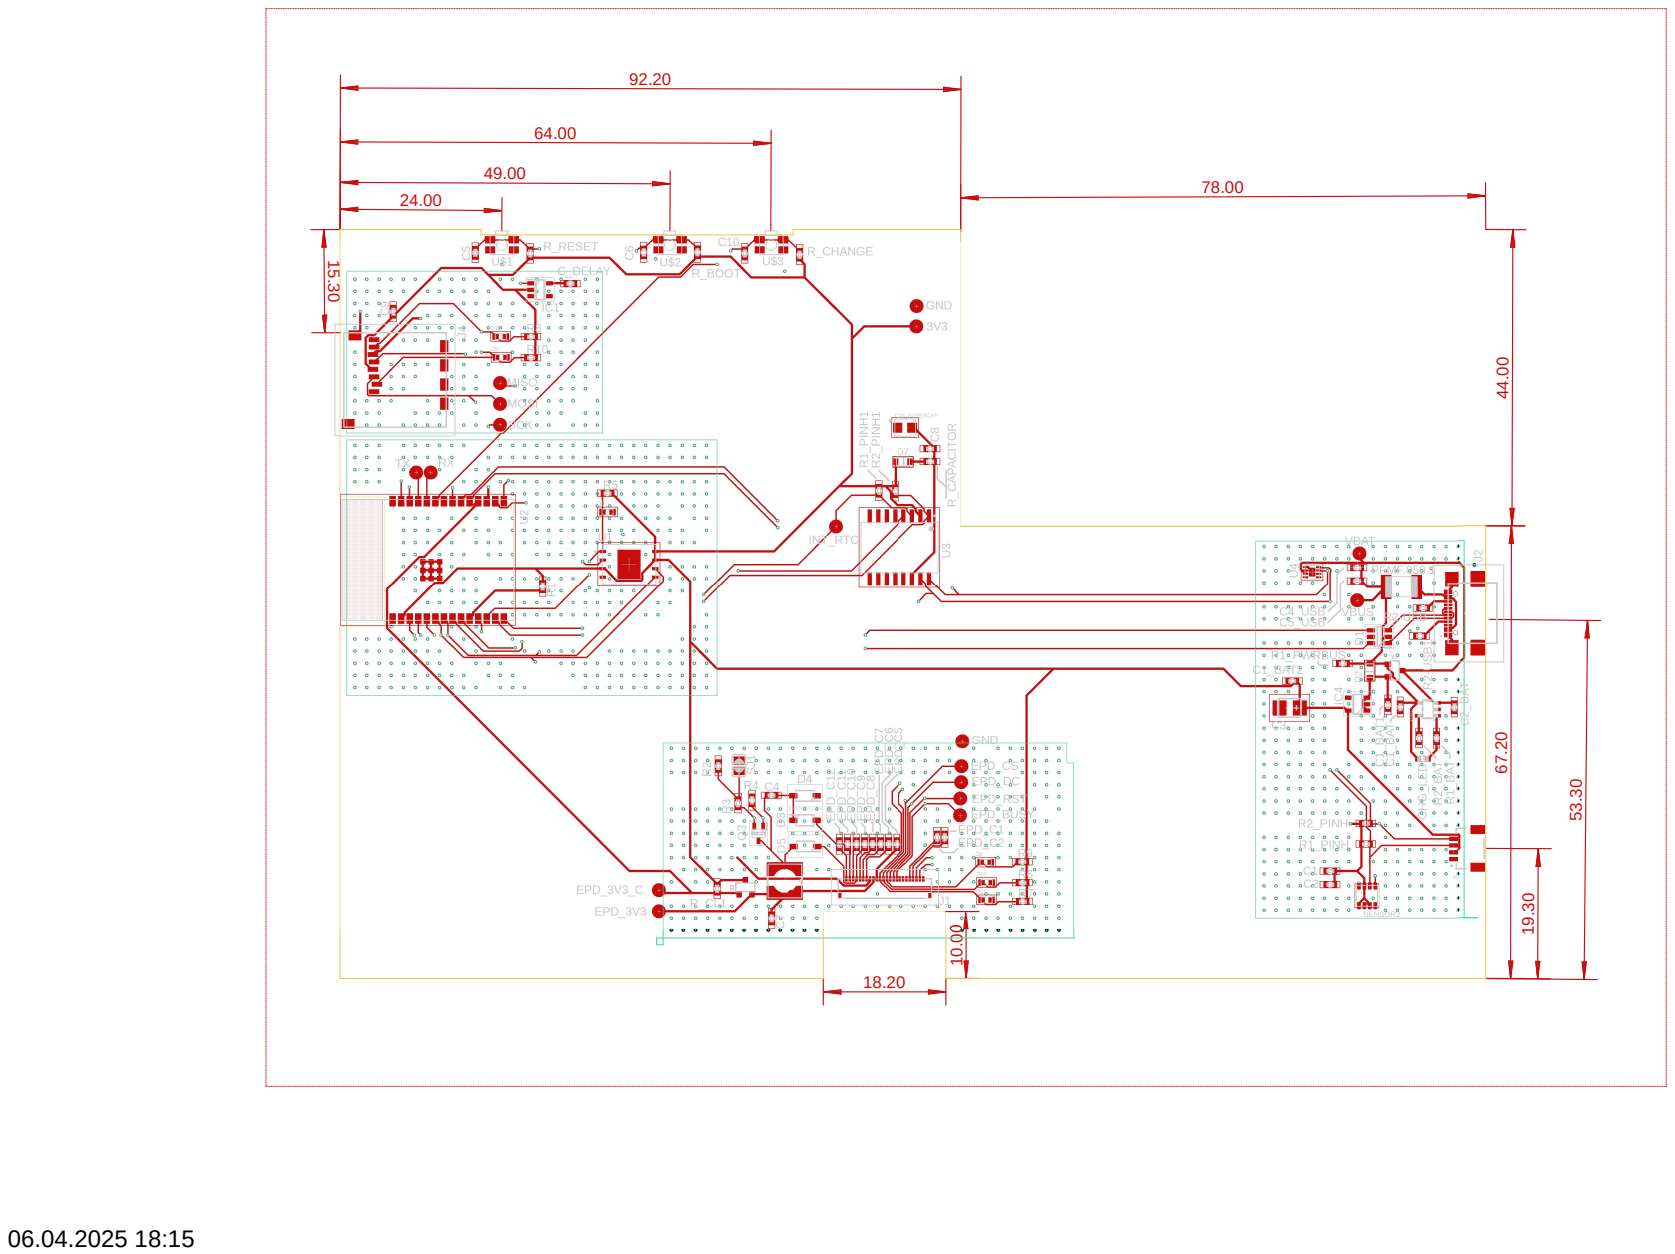
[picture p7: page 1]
C²_BAT C⁷; R_RESET

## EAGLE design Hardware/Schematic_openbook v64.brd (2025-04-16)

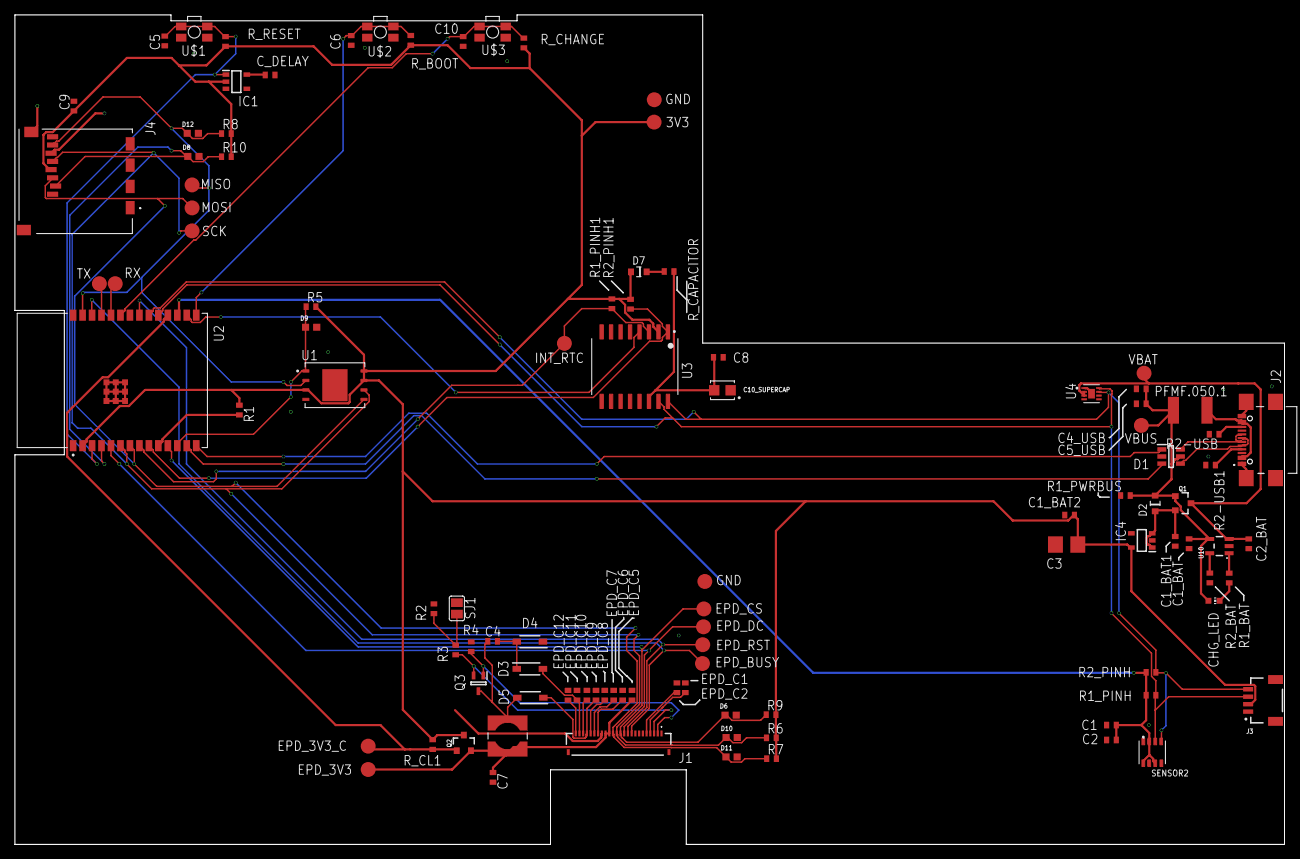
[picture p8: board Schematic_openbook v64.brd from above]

Board: 2 copper layers, 170.2 x 111.2 mm, 103 parts (0 on the bottom side), 55 nets.

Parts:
C1, C2, C4_USB, C6, C8, C9, C10: 100nF; EAGLE-LTSPICE_C0402
C1_BAT, C1_BAT1, C1_BAT2, C2_BAT, C5_USB: 4.7uF; EAGLE-LTSPICE_C0402
C3: 100uF TANT; RCL_CT3528
C4: 4.7uF/25V; EAGLE-LTSPICE_C0402
C5: 1uF; EAGLE-LTSPICE_C0402
C7: 10uF; EAGLE-LTSPICE_C0402
C10_SUPERCAP: CPH3225A; CAPCP3225X100N
CHG_LED: NA; ADAFRUIT_CHIP-LED0603
C_DELAY: 100nF; EAGLE-LTSPICE_C0402
D1: USBLC6-2SC6Y; SOT95P280X145-6N
D2: ESP32_WROVER_AVX---SD0805S020S1R0_AVX_SD0805S020S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; ESP32_WROVER_AVX---SD0805S020S1R0_AVX_SD0805S020S1R0_0
D3, D4, D5: MBR0530; SOD3716X135N
D6, D8, D9, D10, D11, D12: PGB1010603MR; DIOC1608X36N
D7: SD0805S020S1R0; ESP32_WROVER_AVX---SD0805S020S1R0_AVX_SD0805S020S1R0_0
EPD_C1, EPD_C2, EPD_C6, EPD_C7, EPD_C8, EPD_C9, EPD_C10, EPD_C11, EPD_C12: 1uF/50V; EAGLE-LTSPICE_C0402
EPD_C5: 0.1uF/50V; EAGLE-LTSPICE_C0402
IC1: BD5229G-TR; SOT95P280X125-5N
IC4: XC6220A331MR-G; SOT95P280X120-5N
J1: FH34SRJ-24S-0.5SH_99_; FH34SRJ24S05SH99
J2: SAMACSYS_PARTS_USB4110-GF-A; SAMACSYS_PARTS_USB4110GFA
J3: QWIIC_RIGHT_ANGLE; JST04_1MM_RA
J4: 112A-TAAR-R03_ATTEND; 112ATAARR03ATTEND
L1: 68uH; IND_4828-WE-TPC_WRE
PFMF.050.1: ESP32C6_VARISTORCN1812; ESP32C6_VARISTOR_CT/CN1812
Q1, Q2: 20V/4.2A/52mΩ/1.4W; ESP32_WROVER_SPARKFUN-DISCRETESEMI_SOT23-3
Q3: SI1308EDL-T1-GE3; SOT65P210X110-3N
R1, R1_PINH, R1_PINH1, R2_PINH, R2_PINH1, R5, R6, R7, R8, R9, R10: 10K; ESP32_WROVER_EAGLE-LTSPICE_R0402
R1_BAT: 200; ESP32_WROVER_EAGLE-LTSPICE_R0402
R1_PWRBUS: 100K; ESP32_WROVER_EAGLE-LTSPICE_R0402
R2: 2.2; ESP32_WROVER_EAGLE-LTSPICE_R0402
R2-USB, R2-USB1: 5K1; ESP32_WROVER_EAGLE-LTSPICE_R0402
R2_BAT: 2K; ESP32_WROVER_EAGLE-LTSPICE_R0402
R3: 0.47; ESP32_WROVER_EAGLE-LTSPICE_R0402
R4: 10k; ESP32_WROVER_EAGLE-LTSPICE_R0402
R_BOOT: 10K; ESP32_WROVER_EAGLE-LTSPICE_R0402
R_CAPACITOR: 15; ESP32_WROVER_EAGLE-LTSPICE_R0402
R_CHANGE: 10K; ESP32_WROVER_EAGLE-LTSPICE_R0402
R_CL1: 10K; ESP32_WROVER_EAGLE-LTSPICE_R0402
R_RESET: 10K; ESP32_WROVER_EAGLE-LTSPICE_R0402
SENSOR2: BME688; ESP32_WROVER_BME680_PSON80P300X300X100-8N
SJ1: NA; SJ
TP1, TP2, TP3, TP4, TP5, TP6, TP7, TP8, TP9, TP10, TP11, TP12, TP13, TP14, TP15, TP16, TP17: TPTP20R; TP20R
U1: W25Q512JVEIQ; SON127P600X800X80-9N
U2: ESP32-C6-WROOM-1-N8; XCVR_ESP32-C6-WROOM-1-N8
U3: DS3231SN#; SOIC127P1032X265-16N
U4: MAX17048G+T10; SON50P200X200X80-9N
U10: MCP73831; ESP32_WROVER_SPARKFUN-IC-POWER_SOT23-5
U$1: RESET_BUTTON; MYBUTTON
U$2: BOOT_BUTTON; MYBUTTON
U$3: CHANGE_BUTTON; MYBUTTON

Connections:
3V3: C1_BAT2.1, C3.+, C9.1, D7.2, IC1.2, IC4.5, J3.2, J4.P4, Q2.3, R1.1, R1_PINH1.2, R2_PINH1.2, R5.2, R6.2, R7.2, R8.2, R9.2, R10.2, R_BOOT.1, R_CHANGE.1, R_CL1.1, R_RESET.1, TP16.TP, U1.3, U1.7, U1.8, U2.2, U3.2
32KHZ: R2_PINH1.1, U2.9, U3.1
DN: D1.4, J2.A7, J2.B7
DP: D1.6, J2.A6, J2.B6
EPD_3V3: C7.1, EPD_C5.1, J1.15, J1.16, L1.2, Q2.2, TP17.TP
EPD_3V3_C: Q2.1, R_CL1.2, TP13.TP, U2.18
EPD_BUSY: J1.9, TP9.TP, U2.26
EPD_CS: D6.1, J1.12, R9.1, TP10.TP, U2.11
EPD_DC: J1.11, TP11.TP, U2.5
EPD_RST: J1.10, TP12.TP, U2.21
FLASH_CS: D9.1, R5.1, U1.1, U2.12
GDR: J1.2, Q3.1, R4.2
GND: C1.2, C1_BAT.2, C1_BAT1.2, C1_BAT2.2, C2.2, C2_BAT.2, C3.-, C4_USB.2, C5.2, C5_USB.2, C6.2, C7.2, C8.2, C9.2, C10.2, C10_SUPERCAP.1, C_DELAY.2, D1.2, D4.1, D6.2, D8.2, D9.2, D10.2, D11.2, D12.2, EPD_C1.2, EPD_C2.2, EPD_C5.2, EPD_C6.2, EPD_C7.2, EPD_C8.2, EPD_C9.2, EPD_C10.2, EPD_C11.2, EPD_C12.2, IC1.3, IC4.2, J1.8, J1.17, J1.MP1, J1.MP2, J2.A1, J2.A12, J2.B1, J2.B12, J2.MP1, J2.MP2, J2.MP3, J2.MP4, J3.1, J4.G1, J4.G2, J4.G3, J4.G4, J4.P6, R1_PWRBUS.1, R2.1, R2-USB.2, R2-USB1.1, R2_BAT.1, R4.1, SENSOR2.1, SENSOR2.5, SENSOR2.7, SJ1.1, TP4.TP, TP5.TP, U1.4, U1.9, U2.1, U2.28, U2.29_1, U2.29_2, U2.29_3, U2.29_4, U2.29_5, U2.29_6, U2.29_7, U2.29_8, U2.29_9, U3.13, U4.1, U4.4, U4.6, U4.9, U10.2, U$1.1, U$1.2, U$2.1, U$2.2, U$3.1, U$3.2
GPIO8: R1.2, U2.10
I2C_PW: C1.1, C2.1, R1_PINH.2, R2_PINH.2, SENSOR2.2, SENSOR2.6, SENSOR2.8, U2.17
INT_RTC: R1_PINH1.1, TP15.TP, U2.8, U3.3
IO/BOOT: C6.1, R_BOOT.2, U2.15, U$2.3, U$2.4
IO/CHANGE: C10.1, R_CHANGE.2, U2.23, U$3.3, U$3.4
MISO: D12.1, J4.P7, R8.1, TP6.TP, U1.2, U2.27
MOSI: D11.1, J1.14, J4.P3, R7.1, TP7.TP, U1.5, U2.7
unnamed: C1_BAT1.1, D2.1, IC4.1, IC4.3, Q1.2
unnamed: J2.B5, R2-USB.1
unnamed: CHG_LED.C, R1_BAT.1
unnamed: R1_BAT.2, U10.1
unnamed: EPD_C1.1, J1.4
unnamed: J2.A5, R2-USB1.2
unnamed: C4.1, D3.1, D4.2
unnamed: R2_BAT.2, U10.5
unnamed: EPD_C2.1, J1.5
unnamed: EPD_C6.1, J1.18
unnamed: EPD_C7.1, J1.19
unnamed: EPD_C8.1, J1.20
unnamed: C_DELAY.1, IC1.5
unnamed: EPD_C10.1, J1.22
unnamed: D7.1, R_CAPACITOR.1
unnamed: EPD_C12.1, J1.24
PREVGH: D5.1, EPD_C9.1, J1.21
PREVGL: D3.2, EPD_C11.1, J1.23
RESE: J1.3, Q3.2, R3.2
RESE': R2.2, R3.1, SJ1.2
RESET: C5.1, IC1.1, R_RESET.2, U2.3, U$1.3, U$1.4
RTC_RST: U2.16, U3.4
RX: TP2.TP, U2.24
SCK: D10.1, J1.13, J4.P5, R6.1, TP8.TP, U1.6, U2.6
SCL: J3.4, R2_PINH.1, SENSOR2.4, U2.20, U3.16, U4.7
SDA: J3.3, R1_PINH.1, SENSOR2.3, U2.19, U3.15, U4.8
SRC: C4.2, D5.2, L1.1, Q3.3
SS_SD: D8.1, J4.P2, R10.1, U2.4
TX: TP1.TP, U2.25
USB_D+: D1.1, U2.14
USB_D-: D1.3, U2.13
VBAT: C2_BAT.1, Q1.3, TP3.TP, U4.2, U4.3, U10.3
VBUS: C1_BAT.1, C4_USB.1, C5_USB.1, CHG_LED.A, D1.5, D2.2, PFMF.050.1.2, Q1.1, R1_PWRBUS.2, TP14.TP, U10.4
VRTC: C8.1, C10_SUPERCAP.2, R_CAPACITOR.2, U3.14
VUSB: J2.A4, J2.A9, J2.B4, J2.B9, PFMF.050.1.1

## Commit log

2025-04-06 Initial commit (EVD Done)
    [BOM_README.xlsx, BOM_Schematic_openbook v58.csv, PnP_Schematic_openbook v58_front.csv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]
2025-04-13 Fixed (Review #1)
    [Schematic_openbook v62.brd, Schematic_openbook_v58.sch]
2025-04-16 Missing via stiching to a component
    [Schematic_openbook v64.brd]

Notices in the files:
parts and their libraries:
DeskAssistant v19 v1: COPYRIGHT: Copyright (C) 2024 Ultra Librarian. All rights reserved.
